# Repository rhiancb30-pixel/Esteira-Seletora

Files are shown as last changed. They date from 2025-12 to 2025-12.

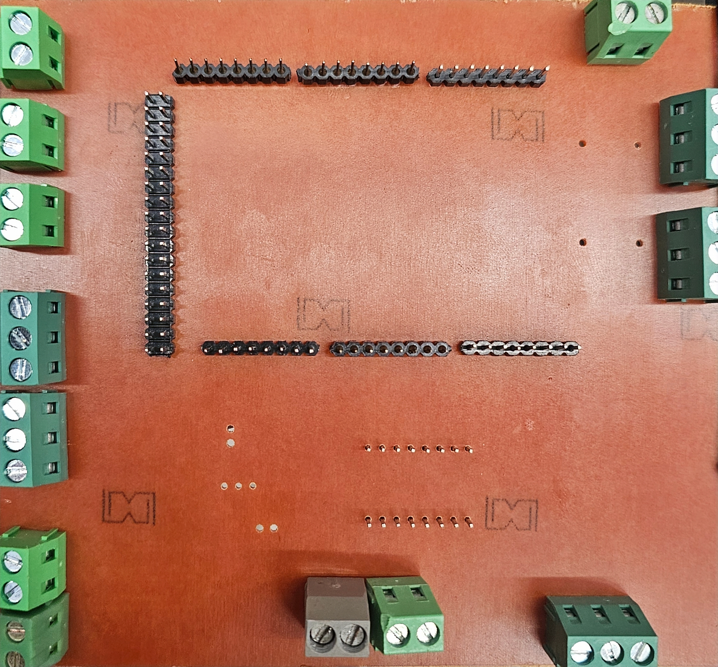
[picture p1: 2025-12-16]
Imagens do Projeto/PlacaA.jpg

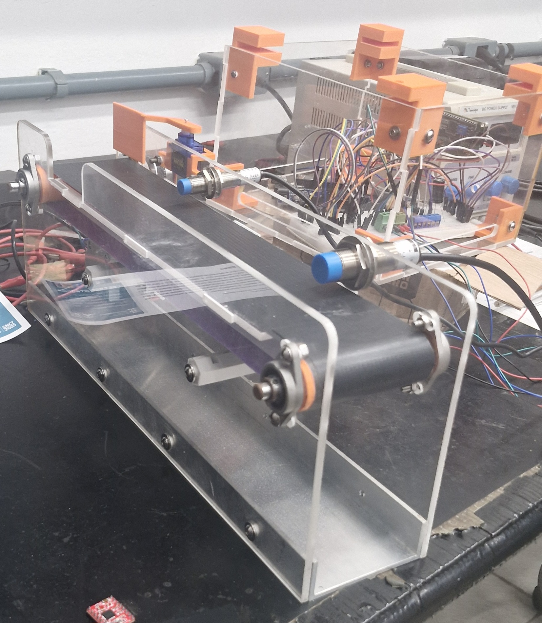
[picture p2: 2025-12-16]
Imagens do Projeto/20251215_132240.jpg

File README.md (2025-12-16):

# Esteira Seletora Linear

## 📌 Descrição do Projeto

Este repositório apresenta o desenvolvimento de uma **Esteira Seletora Linear**, criada como projeto didático para o Curso de Engenharia Mecatrônica do **Instituto Federal de Santa Catarina (IFSC)**, no contexto da disciplina **Projeto Integrador Eletromecânico**.

O objetivo principal do projeto é proporcionar aos alunos uma experiência prática próxima à realidade industrial, integrando conceitos de **mecânica, eletrônica e programação**, por meio de um sistema automatizado, modular e de baixo custo.

A esteira é capaz de **transportar, identificar, contar e separar peças metálicas e não metálicas**, exibindo informações de funcionamento em uma interface homem-máquina (IHM) com display LCD.

---

## 🎯 Objetivos

* Desenvolver um equipamento didático inspirado em sistemas industriais reais;
* Aplicar conhecimentos multidisciplinares (mecânica, eletrônica e programação);
* Criar uma solução **modular**, **expansível** e **replicável**;
* Disponibilizar **documentação aberta** para uso e aprimoramento por outros estudantes.

---

## ⚙️ Funcionalidades Principais

* Transporte contínuo de peças por esteira;
* Contagem total de peças;
* Identificação de peças metálicas;
* Separação automática das peças por meio de servo motor;
* Exibição de dados no display LCD (quantidade de peças, estado do motor);
* Arquitetura modular, permitindo a adição de novos sensores e atuadores.

---

## 🧩 Arquitetura do Sistema

O sistema é dividido em dois módulos principais:

### 🔹 Caixa Elétrica

* Arduino Mega (controlador principal);
* Display LCD 16x2 com interface I2C;
* Botões de controle;
* Placa de circuito impresso (PCB);
* Fonte de alimentação 12 V;

### 🔹 Esteira Seletora

* Estrutura em acrílico e perfis de alumínio;
* Motor de passo com driver TB6600;
* Servo motor SG90 para separação;
* Sensor capacitivo (contagem);
* Sensor indutivo (detecção de metal);
* Lona em PVC e roletes impressos em 3D.

---

## 🛠️ Tecnologias Utilizadas

### Hardware

* Arduino Mega
* Motor de passo + Driver TB6600
* Servo motor SG90
* Sensor capacitivo
* Sensor indutivo
* Display LCD 16x2 (I2C)

### Software

* Linguagem **C++** (Arduino)
* Bibliotecas:

  * `AccelStepper`
  * `Servo`
  * `LiquidCrystal_I2C`

### Ferramentas

* SolidWorks (modelagem mecânica)
* Proteus (esquemático e PCB)
* Impressão 3D (peças estruturais)
* Corte a laser (acrílico)

---

## 📂 Estrutura do Repositório

```
Esteira-Seletora-Linear/
│
├── Documentação/
│   └── Projeto_Integrador.pdf        # Relatório final do projeto (ou versão em .docx)
│
├── Imagens do Projeto/
│   ├── prototipo_montado.jpg
│   ├── caixa_eletrica.jpg
│   ├── esteira_montada.jpg
│   └── esquematico_geral.png
│
├── Desenho técnico/
│   ├── Caixa/
│   │   ├── tampa_caixa.pdf
│   │   ├── lateral_caixa.pdf
│   │   └── base_caixa.pdf
│   │
│   └── Esteira/
│       ├── lateral_esteira.pdf
│       ├── eixo_motor.pdf
│       ├── eixo_movido.pdf
│       └── seletor_servo.pdf
│
├── dxf/
│   ├── caixa/
│   │   └── *.dxf                     # Arquivos DXF para corte a laser
│   └── esteira/
│       └── *.dxf
│
├── stl/
│   ├── cantoneiras/
│   │   └── *.stl                     # Peças impressas em 3D
│   ├── roletes/
│   │   └── *.stl
│   └── suportes/
│       └── *.stl
│
├── Eletronica PI/
│   ├── pcb/
│   │   └── layout_pcb.pdf
│   └── componentes/
│       └── lista_componentes.xlsx
│
├── Proteus/
│   ├── Esquematico1/
│   │   └── *.pdsprj                  # Versões iniciais / testes
│   │
│   └── EsquematicoPI/
│       └── *.pdsprj                  # Esquemático final do projeto
│
├── firmware/
│   └── esteira_seletora.ino           # Código Arduino
│
├── README.md
└── LICENSE

```

---

## 🚀 Como Utilizar

1. Monte a estrutura mecânica conforme os desenhos técnicos;
2. Realize a montagem elétrica com base no esquemático;
3. Carregue o código no Arduino Mega;
4. Ajuste sensores e atuadores conforme a aplicação;
5. Utilize o sistema em atividades didáticas ou como base para novos projetos.

---

## 🔧 Possíveis Melhorias Futuras

* Adição de sensor de cor RGB;
* Implementação de sistema de visão computacional;
* Classificação por múltiplos critérios (material + cor);
* Modularização da eletrônica em placas dedicadas;
* Integração com CLP para uso em aulas avançadas.

---

## 👨‍💻 Autores

* Alex Gabriel Claure Escobar
* Elisa Klosinski dos Santos
* Helio Henrique Hinckel Filho
* Rhian Eric Cabral Branco

---

## 🏫 Instituição

**Instituto Federal de Santa Catarina (IFSC)**
Curso de Engenharia Mecatrônica
Projeto Integrador Eletromecânico – 2025

---

## 📜 Licença

Este projeto é disponibilizado para fins **educacionais e acadêmicos**. Sinta-se à vontade para estudar, adaptar e evoluir a solução, citando os autores e a instituição quando aplicável.

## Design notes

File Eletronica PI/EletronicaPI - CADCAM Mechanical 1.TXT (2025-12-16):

G04 PROTEUS RS274X GERBER FILE*
%FSLAX24Y24*%
%MOIN*%
%ADD24C,0.0080*%
G54D24*
X-60500Y+7500D02*
X-5500Y+7500D01*
X-5500Y+50500D01*
X-60500Y+50500D01*
X-60500Y+7500D01*
M00*

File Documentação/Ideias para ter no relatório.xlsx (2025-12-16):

Ideias
Manutenção
Modulação
Sugestão de melhoria
https://www.canva.com/design/DAG2VoPyCwE/Shcb8VvLO4bGqYgUN-yBwA/edit

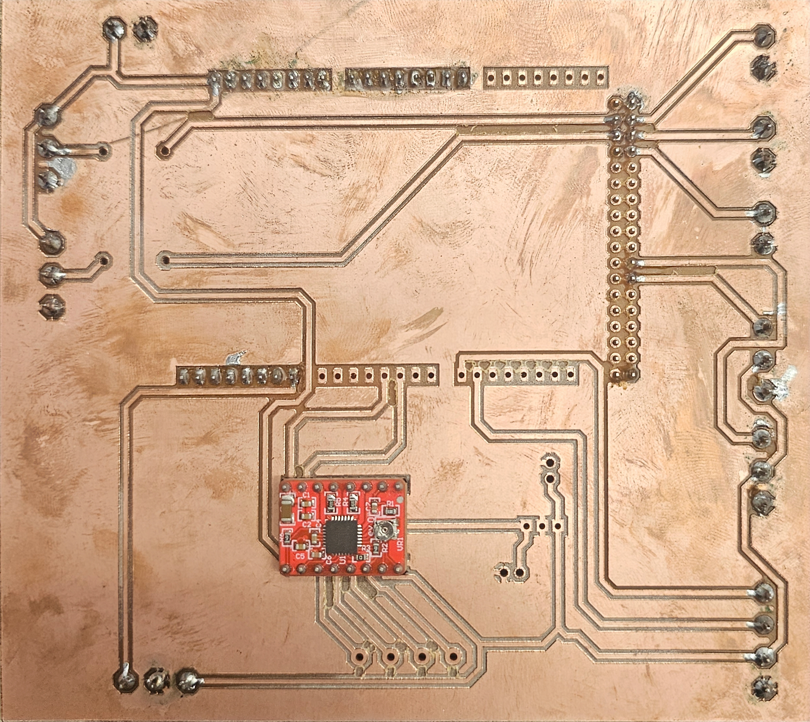
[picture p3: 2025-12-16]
Imagens do Projeto/PlacaB.jpg

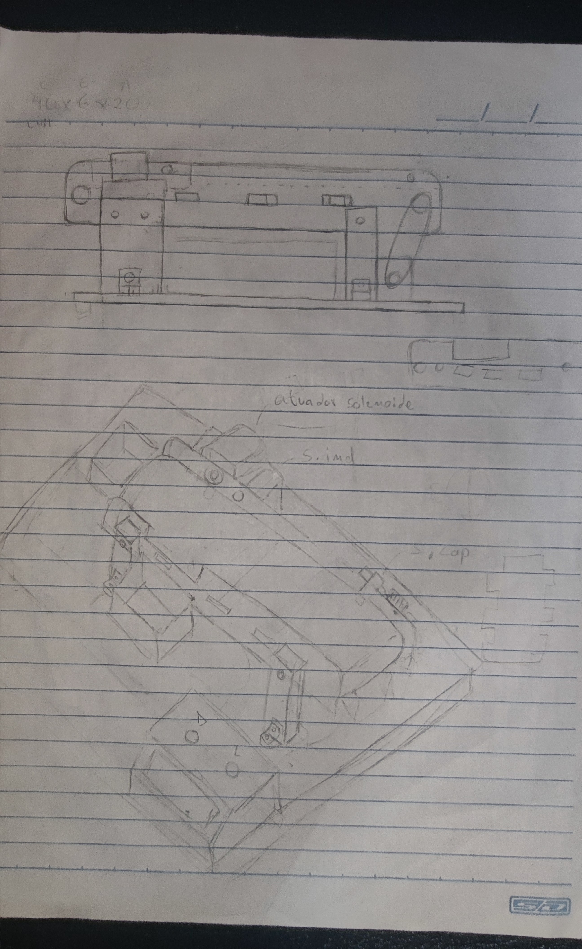
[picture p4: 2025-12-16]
Imagens do Projeto/Esboço da esteira.jpg

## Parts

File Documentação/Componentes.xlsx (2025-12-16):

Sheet: Página1
Componente | Valores | Link Cad
Fonte de Alimentação 12V (https://produto.mercadolivre.com.br/MLB-2786638151-fonte-de-alimentaco-12v-2a-bivolt-acdc-adapter-_JM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) | R$0.00 | x
Acrílico | R$0.00 | x
Motor de Passo | R$0.00 | https://drive.google.com/file/d/1ImsmihgE60tYiPbwnQAOw_tTxuTRrptJ/view?usp=drive_link
Servo Motor - SG90 (https://www.mercadolivre.com.br/mini-servo-9g-180-servomotor-sg90-para-arduino-drone-heli/p/MLB34434502) | R$19.00 | https://grabcad.com/library/motor-de-passo-nema17-1
Rolete traseiro | R$0.00 | https://drive.google.com/file/d/1i1CdFmntgAyyUeiQMpFU783zIE5ebJbq/view?usp=drive_link
Lona | R$0.00 | https://drive.google.com/file/d/1nnzfvkRSEqwytu2aUfeKmrAbUZm7iBYa/view?usp=drive_link
Arduino Mega | R$0.00 | https://drive.google.com/file/d/1uFck1UgpN9d7dUV1sjb8ttN3lQ05RABe/view?usp=drive_link
Sensor capacitivo (https://www.mercadolivre.com.br/sensor-capacitivo-ljc18a3bzax-dc636v-3-fios-npn-nf/up/MLBU604159364) | R$70.97 | https://drive.google.com/file/d/1xE6i0U9dVBmDGzSRF0fsskQny3ayWI2L/view?usp=drive_link
Display LCD - I2C | R$0.00 | https://drive.google.com/file/d/1ZexDDSDv5DjEdKzy_C0O0FfySXnyb1nx/view?usp=drive_link
Sensor indutivo | R$0.00 | https://drive.google.com/file/d/1xE6i0U9dVBmDGzSRF0fsskQny3ayWI2L/view?usp=drive_link
Driver de motor (https://www.mercadolivre.com.br/driver-motor-de-passo-a4988-p-cnc-impressora-3d-reprap/p/MLB38335569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) | R$15.00 | A4988 Stepper Driver - With Pins & Socketed | 3D CAD Model Library | GrabCAD (https://grabcad.com/library/a4988-stepper-driver-with-pins-socketed-1)
Botão De Pressão (3x) | R$0.00 | x
Polia GT2 20t (https://produto.mercadolivre.com.br/MLB-2112036543-2-polias-gt2-20-dentes-p-correia-6mm-furos-5-6-635-8-mm-_JM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) | R$23.90 | https://drive.google.com/file/d/1iuYczG9JG5Oh3zLpm2U_dMAc3bwXQJ-2/view?usp=drive_link
Polia GT2 40t (https://produto.mercadolivre.com.br/MLB-2112036543-2-polias-gt2-20-dentes-p-correia-6mm-furos-5-6-635-8-mm-_JM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) | R$23.90 | https://drive.google.com/file/d/16gqqD69uVRsaSKja5BieEQMrk8KKjpvp/view?usp=drive_link
Mancal KFL08 (https://www.impactocnc.com/mancal-com-rolamento-kfl08-eixo-8mm) | R$0.00 | https://drive.google.com/file/d/1nWoQvLEezi6RtFR1NJ_Xth8WYlq0R2Wl/view?usp=drive_link
Regulador de Tensão | R$0.00 | x
Correia GT2 6mm com passo 2mm - Alma de aço (https://www.impactocnc.com/correia-gt2-6mm-com-passo-2mm-alma-de-aco) | R$7.90 | x
Soma | R$160.67

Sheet: Página2
Alternativas | Economia | Disponibilidade | Versatilidade | Fabricabilidade | Durabilidade | Total
Fonte de Alimentação 12V | 8 | 10 | 9 | 9 | 9 | 45
Fonte de Alimentação 24V | 7 | 5 | 4 | 9 | 9 | 34
Fonte de Alimentação 5V | 8 | 10 | 5 | 8 | 7 | 38
Alternativas | Economia | Disponibilidade | Versatilidade | Fabricabilidade | Durabilidade | Total
Acrílico | 3 | 5 | 8 | 4 | 7 | 27
MDF | 5 | 5 | 7 | 5 | 4 | 26
Perfil de Alumínio | 1 | 5 | 8 | 4 | 7 | 25
Alternativas | Economia | Disponibilidade | Versatilidade | Fabricabilidade | Durabilidade | Total
Motor de Passo | 5 | 10 | 10 | 9 | 8 | 42
Motor CC | 6 | 10 | 8 | 9 | 6 | 39
Alternativas | Economia | Disponibilidade | Versatilidade | Fabricabilidade | Durabilidade | Total
Rolete traseiro | 8 | 10 | 1 | 7 | 6 | 32
Engrenagem | 8 | 10 | 1 | 6 | 6 | 31
Polia | 7 | 5 | 1 | 5 | 9 | 27
Alternativas | Economia | Disponibilidade | Versatilidade | Fabricabilidade | Durabilidade | Total
Lona | 10 | 10 | 5 | 9 | 5 | 39
Impressão 3D | 5 | 10 | 10 | 2 | 7 | 34
Nylon | 5 | 1 | 5 | 9 | 8 | 28
Alternativas | Economia | Disponibilidade | Versatilidade | Fabricabilidade | Durabilidade | Total
Arduino Mega | 3 | 10 | 9 | 9 | 7 | 38
Arduino Nano | 6 | 10 | 6 | 9 | 6 | 37
ESP | 5 | 1 | 10 | 9 | 6 | 31
Alternativas | Economia | Disponibilidade | Versatilidade | Fabricabilidade | Durabilidade | Total
Sensor capacitivo | 5 | 1 | 8 | 9 | 7 | 30
Sensor indutivo | 6 | 2 | 4 | 9 | 7 | 28
Célula de carga | 4 | 1 | 6 | 6 | 8 | 25
Alternativas | Economia | Disponibilidade | Versatilidade | Fabricabilidade | Durabilidade | Total
Display LCD - I2C | 7 | 5 | 10 | 9 | 4 | 35
Display LCD | 9 | 1 | 8 | 9 | 3 | 30
Display de sete segmentos | 10 | 10 | 2 | 9 | 2 | 33
Alternativas | Economia | Disponibilidade | Versatilidade | Fabricabilidade | Durabilidade | Total
Sensor indutivo | 5 | 1 | 7 | 9 | 7 | 29
Sensor capacitivo | 5 | 1 | 6 | 9 | 7 | 28
Sistema de Visão | 1 | 1 | 10 | 9 | 7 | 28
Alternativas | Economia | Disponibilidade | Versatilidade | Fabricabilidade | Durabilidade | Total
Servo Motor - SG90 | 6 | 5 | 5 | 9 | 7 | 32
Atuador Solenóide | 10 | 1 | 3 | 9 | 3 | 26

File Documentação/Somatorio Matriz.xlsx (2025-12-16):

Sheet: Página1
Alternativas | Economia | Disponibilidade | Versatilidade | Fabricabilidade | Durabilidade | Total | Column 1 | Column 2 | Column 3 | Column 4 | Column 5 | Column 6 | Column 7 | Alternativas | Economia | Disponibilidade | Versatilidade | Fabricabilidade | Durabilidade | Total
Fonte de Alimentação 12V | 8 | 10 | 9 | 9 | 9 | 45 | Fonte de Alimentação 5V | 8 | 10 | 5 | 8 | 7 | 38 | Fonte de Alimentação 24V | 7 | 5 | 4 | 9 | 9 | 34
Acrílico | 3 | 5 | 8 | 4 | 7 | 27 | Acrílico | 3 | 5 | 8 | 4 | 7 | 27 | MDF | 5 | 5 | 7 | 5 | 4 | 26
Motor de Passo | 5 | 10 | 10 | 9 | 8 | 42 | Motor CC | 6 | 10 | 8 | 9 | 6 | 39 | Motor de Passo | 5 | 10 | 10 | 9 | 8 | 42
Rolete traseiro | 8 | 10 | 1 | 7 | 6 | 32 | Engrenagem | 8 | 10 | 1 | 7 | 6 | 32 | Polia | 7 | 5 | 1 | 5 | 9 | 27
Lona | 10 | 10 | 5 | 9 | 5 | 39 | Impressão 3D | 5 | 10 | 10 | 2 | 7 | 34 | Nylon | 5 | 1 | 5 | 9 | 8 | 28
Arduino Mega | 2 | 10 | 9 | 9 | 7 | 37 | Arduino Nano | 6 | 10 | 6 | 9 | 6 | 37 | ESP | 5 | 1 | 10 | 9 | 6 | 31
Sensor capacitivo | 5 | 1 | 8 | 9 | 7 | 30 | Sensor capacitivo | 5 | 1 | 8 | 9 | 7 | 30 | Célula de carga | 4 | 1 | 7 | 9 | 8 | 29
Display LCD - I2C | 7 | 5 | 10 | 9 | 4 | 35 | Display LCD | 9 | 1 | 8 | 9 | 3 | 30 | Display de sete segmentos | 10 | 10 | 2 | 9 | 2 | 33
Sensor indutivo | 5 | 1 | 7 | 9 | 7 | 29 | Sensor indutivo | 5 | 1 | 7 | 9 | 7 | 29 | Sistema de Visão | 1 | 1 | 10 | 9 | 7 | 28
Servo Motor - SG90 | 6 | 5 | 5 | 9 | 7 | 32 | Atuador Solenóide | 10 | 1 | 3 | 9 | 3 | 26 | Atuador Solenóide | 10 | 1 | 3 | 9 | 3 | 26
Soma | 59 | 67 | 72 | 83 | 67 | 348 | Soma | 65 | 59 | 64 | 75 | 59 | 322 | Soma | 59 | 40 | 59 | 82 | 64 | 304

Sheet: Página2
Alternativas | Economia | Disponibilidade | Versatilidade | Fabricabilidade | Durabilidade | Total
Fonte de Alimentação 12V | 8 | 10 | 9 | 9 | 9 | 45
Fonte de Alimentação 24V | 7 | 5 | 4 | 9 | 9 | 34
Fonte de Alimentação 5V | 8 | 10 | 5 | 8 | 7 | 38
Alternativas | Economia | Disponibilidade | Versatilidade | Fabricabilidade | Durabilidade | Total
Acrílico | 3 | 5 | 8 | 4 | 7 | 27
MDF | 5 | 5 | 7 | 5 | 4 | 26
Perfil de Alumínio | 1 | 5 | 8 | 4 | 7 | 25
Alternativas | Economia | Disponibilidade | Versatilidade | Fabricabilidade | Durabilidade | Total
Motor de Passo | 5 | 10 | 10 | 9 | 8 | 42
Motor CC | 6 | 10 | 8 | 9 | 6 | 39
Alternativas | Economia | Disponibilidade | Versatilidade | Fabricabilidade | Durabilidade | Total
Rolete traseiro | 8 | 10 | 1 | 7 | 6 | 32
Engrenagem | 8 | 10 | 1 | 6 | 6 | 31
Polia | 7 | 5 | 1 | 5 | 9 | 27
Alternativas | Economia | Disponibilidade | Versatilidade | Fabricabilidade | Durabilidade | Total
Lona | 10 | 10 | 5 | 9 | 5 | 39
Impressão 3D | 5 | 10 | 10 | 2 | 7 | 34
Nylon | 5 | 1 | 5 | 9 | 8 | 28
Alternativas | Economia | Disponibilidade | Versatilidade | Fabricabilidade | Durabilidade | Total
Arduino Mega | 3 | 10 | 9 | 9 | 7 | 38
Arduino Nano | 6 | 10 | 6 | 9 | 6 | 37
ESP | 5 | 1 | 10 | 9 | 6 | 31
Alternativas | Economia | Disponibilidade | Versatilidade | Fabricabilidade | Durabilidade | Total
Sensor capacitivo | 5 | 1 | 8 | 9 | 7 | 30
Sensor indutivo | 6 | 2 | 4 | 9 | 7 | 28
Célula de carga | 4 | 1 | 6 | 6 | 8 | 25
Alternativas | Economia | Disponibilidade | Versatilidade | Fabricabilidade | Durabilidade | Total
Display LCD - I2C | 7 | 5 | 10 | 9 | 4 | 35
Display LCD | 9 | 1 | 8 | 9 | 3 | 30
Display de sete segmentos | 10 | 10 | 2 | 9 | 2 | 33
Alternativas | Economia | Disponibilidade | Versatilidade | Fabricabilidade | Durabilidade | Total
Sensor indutivo | 5 | 1 | 7 | 9 | 7 | 29
Sensor capacitivo | 5 | 1 | 6 | 9 | 7 | 28
Sistema de Visão | 1 | 1 | 10 | 9 | 7 | 28
Alternativas | Economia | Disponibilidade | Versatilidade | Fabricabilidade | Durabilidade | Total
Servo Motor - SG90 | 6 | 5 | 5 | 9 | 7 | 32
Atuador Solenóide | 10 | 1 | 3 | 9 | 3 | 26

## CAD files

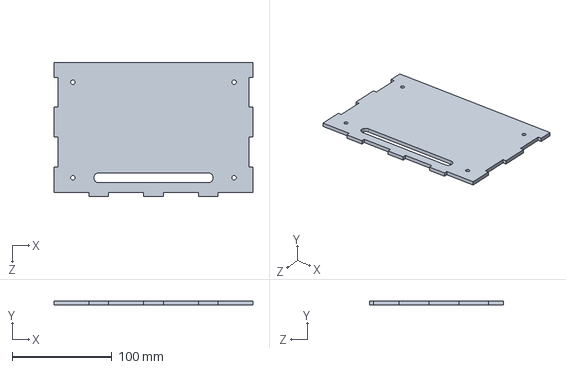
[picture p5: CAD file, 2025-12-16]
Caixa/[Ajustado] lateral fundo.SLDPRT
200.0 x 4.00 x 135.0 mm

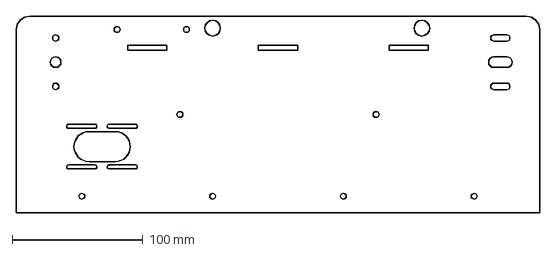
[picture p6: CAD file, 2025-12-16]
dxf/LateralB.DXF
400.0 x 150.0 mm

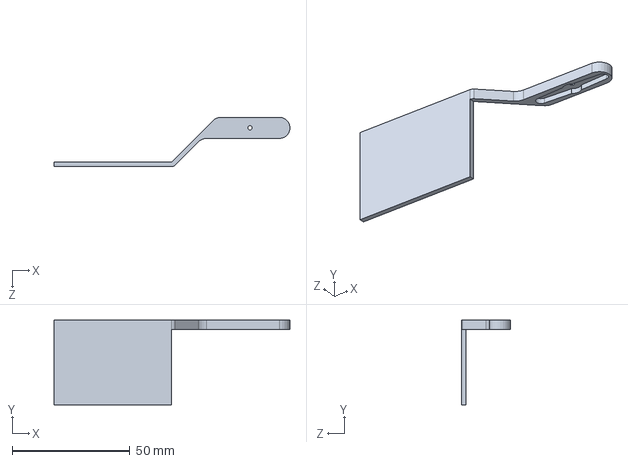
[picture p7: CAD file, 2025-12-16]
Esteira/seletorservo1.0.SLDPRT
100.4 x 36.0 x 21.0 mm

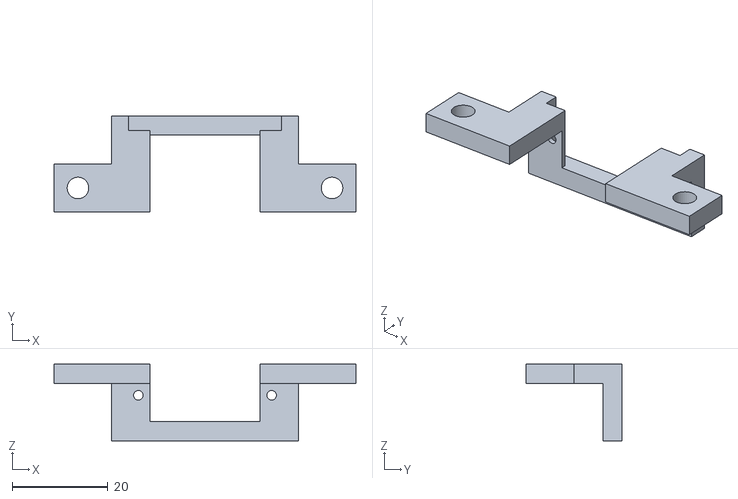
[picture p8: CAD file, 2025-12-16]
stl/suporteServo1.0.STL
63.0 x 20.0 x 16.0

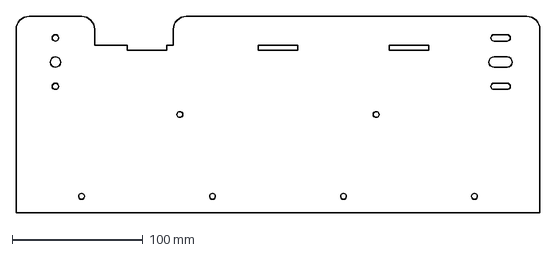
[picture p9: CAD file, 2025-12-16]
dxf/LateralSaida.DXF
400.0 x 150.0 mm

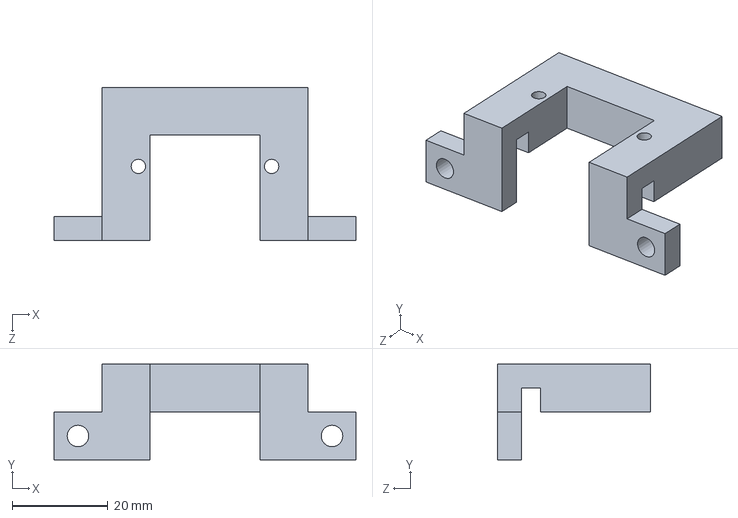
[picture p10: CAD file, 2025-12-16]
Esteira/suporte servomotor.SLDPRT
63.0 x 20.0 x 32.0 mm

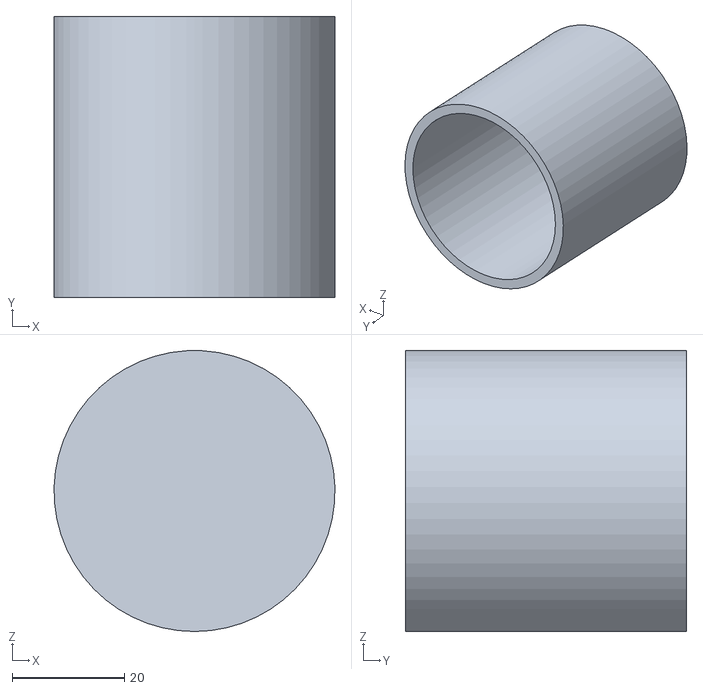
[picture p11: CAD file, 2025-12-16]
stl/Peça2.STL
50.0 x 50.0 x 50.0

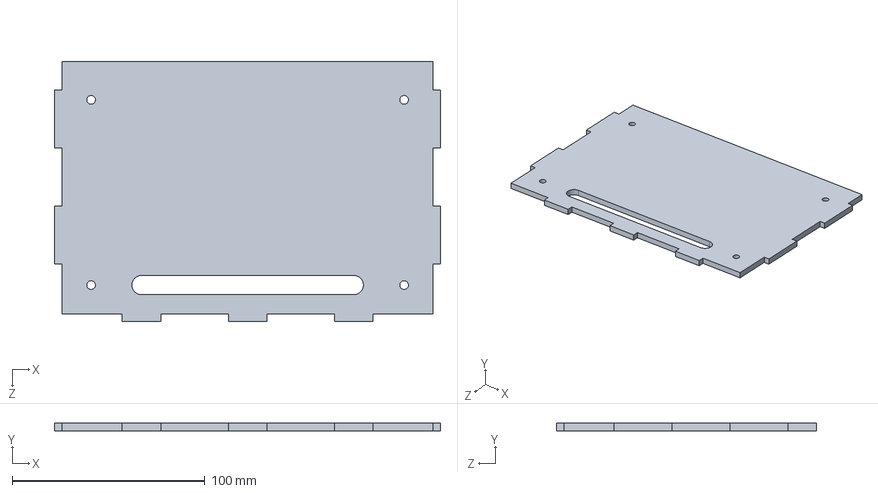
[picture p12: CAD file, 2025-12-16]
Caixa/lateral.SLDPRT
200.1 x 4.00 x 135.0 mm

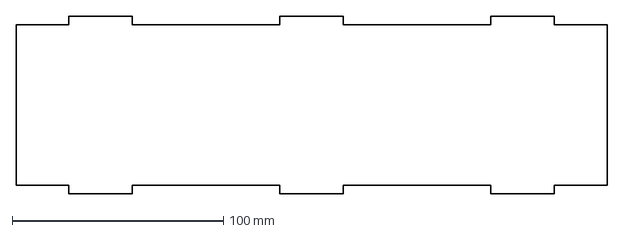
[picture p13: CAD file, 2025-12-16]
dxf/TetoFixador.DXF
280.0 x 84.0 mm

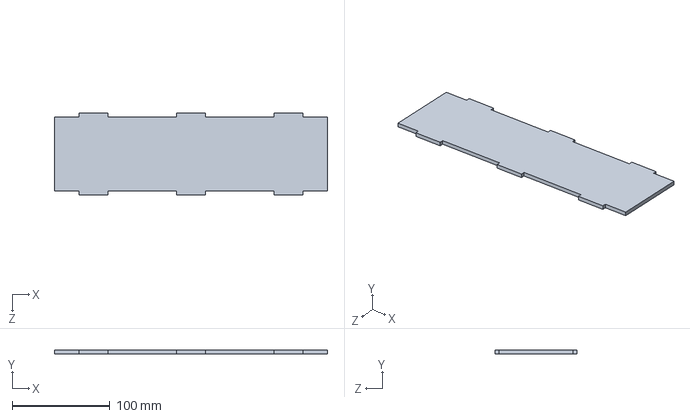
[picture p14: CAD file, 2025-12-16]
Esteira/TetoFixador.SLDPRT
280.0 x 4.00 x 84.0 mm

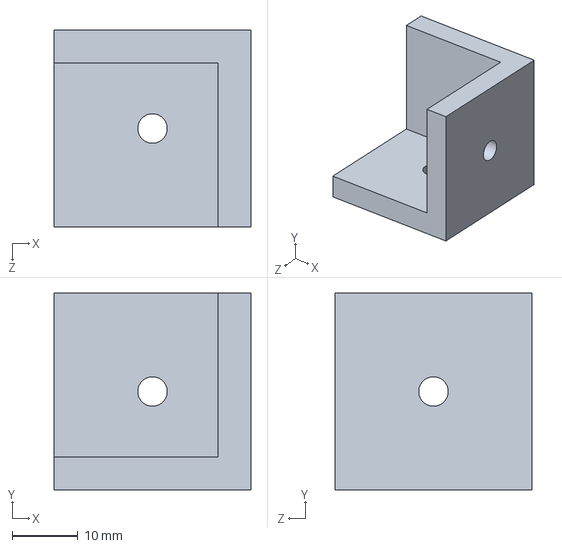
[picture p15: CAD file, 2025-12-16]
Caixa/cantoneira_2.SLDPRT
30.0 x 30.0 x 30.0 mm

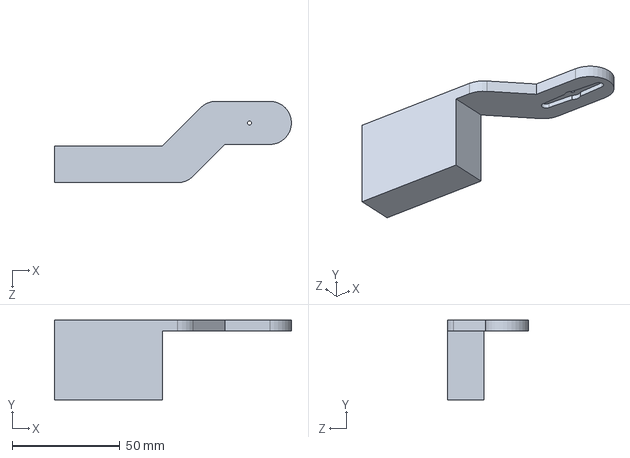
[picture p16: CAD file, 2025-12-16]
Esteira/seletorservo.SLDPRT
109.7 x 37.0 x 37.7 mm

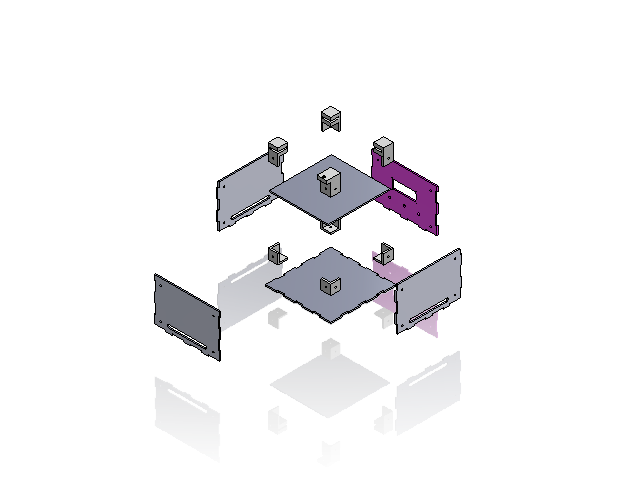
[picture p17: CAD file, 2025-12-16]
Caixa/Caixa.SLDASM
Base
lateral x 2
[Ajustado] lateral fundo
cantoneira_2 x 4
cantoneira_1 x 2
cantoneira_3
lateral LCD
cantoneira com trava
TampaCaixa

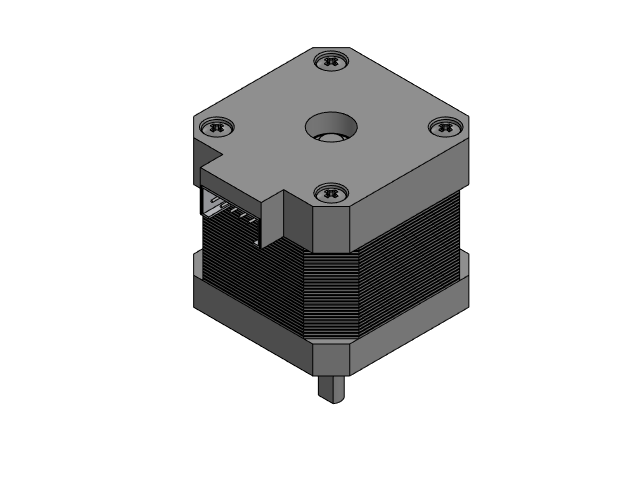
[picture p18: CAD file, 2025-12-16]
Esteira/NEMA17 STEPPER MOTOR.SLDASM
Part1_1.stp
Part2_1.stp
Part3_1.stp
Part4_1.stp x 29
Part5_1.stp
Part6_1.stp x 2
Part7_1.stp
DIN 7985 (H) - M3x30-H_1.stp x 4
Part8_1.stp
Part9_1.stp x 6
Part10_1.stp x 2

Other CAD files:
Esteira/GT2_40T_8mm-Bore_6mm-Belt v2.SLDASM
stl/seletorservo1.0.STL
Caixa/lateral fundo.SLDPRT
Esteira/suporteServo1.0.SLDPRT
Caixa/Base.SLDPRT
Caixa/TampaCaixa.SLDPRT
Caixa/cantoneira com trava.SLDPRT
Caixa/cantoneira_1.SLDPRT
Caixa/cantoneira_2 com m3 esquerdo.SLDPRT
Caixa/cantoneira_2 com m3.SLDPRT
Caixa/cantoneira_3.SLDPRT
Caixa/cantoneira_4.SLDPRT
Caixa/cantonera.SLDPRT
Caixa/lateral LCD.SLDPRT
Desenho técnico/Caixa/Base.SLDDRW
Desenho técnico/Caixa/Caixa.SLDDRW
Desenho técnico/Caixa/[Ajustado] TampaCaixa.SLDDRW
Desenho técnico/Caixa/[Ajustado] lateral fundo.SLDDRW
Desenho técnico/Caixa/cantoneira com trava.SLDDRW
Desenho técnico/Caixa/cantoneira_1.SLDDRW
Desenho técnico/Caixa/cantoneira_2.SLDDRW
Desenho técnico/Caixa/cantoneira_4.SLDDRW
Desenho técnico/Caixa/lateral LCD.SLDDRW
Desenho técnico/Caixa/lateral.SLDDRW
Desenho técnico/Esteira/Espacador.SLDDRW
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

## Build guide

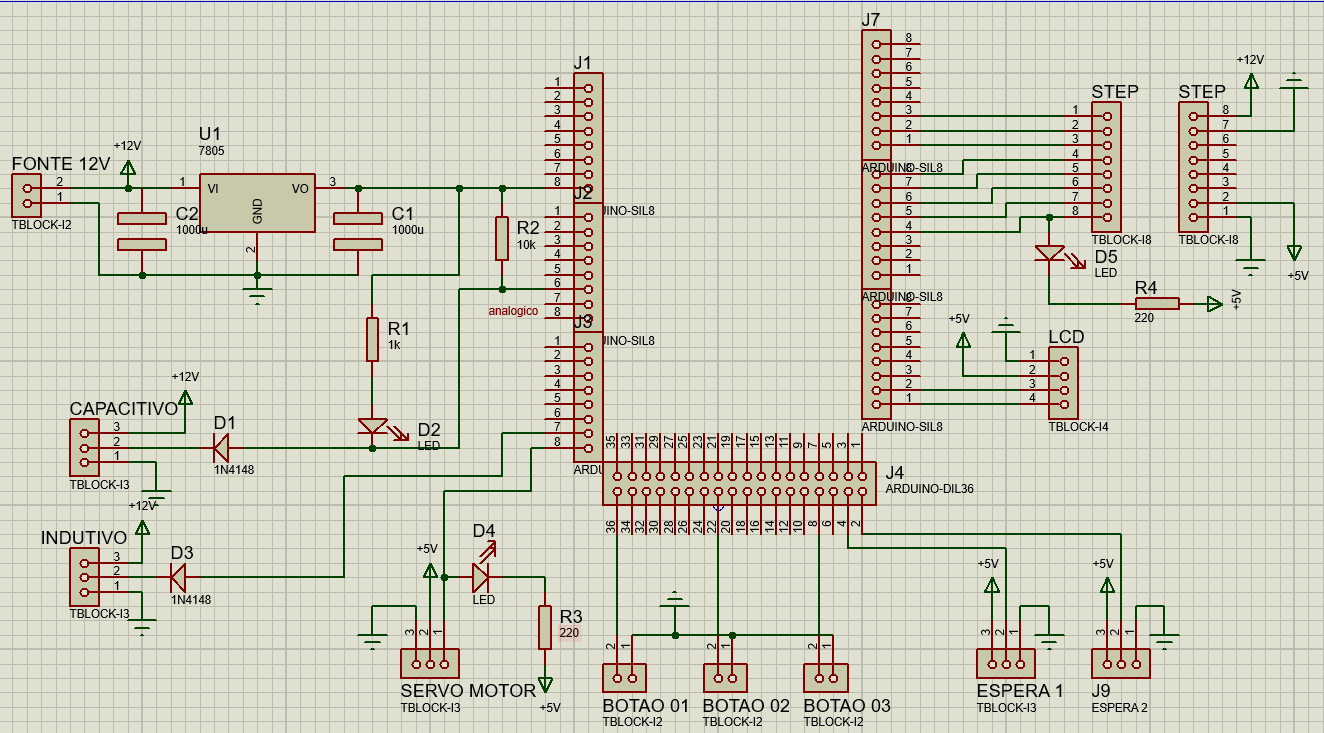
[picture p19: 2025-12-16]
Proteus/PrintProteus.png
